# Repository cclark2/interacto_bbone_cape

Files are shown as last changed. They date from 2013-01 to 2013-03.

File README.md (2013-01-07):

Interacto BeagleBone Cape
=========================

Get your BeagleBone interactive with a triple axis accelerometer, gyroscope, and magnetometer, plus a 640x480 30fps camera! All sensors are digital and communicate via I2C to the BeagleBone. The camera frames are captured using the PRU.

Special thanks to <a href="http://www.sparkfun.com/">SparkFun</a> for use of their open-source EAGLE libraries.

## Project Links
- <a href="http://www.hitchhikeree.org/beaglebone_capes/interacto/">HitchhikerEE page</a>
- <a href="http://www.youtube.com/watch?v=t2w74zxGNqg">YouTube video</a>
- <a href="https://docs.google.com/folder/d/0B5HjtPsFD8u5ZUltQlZ1RDNVN1U/edit">Design files on Google Drive</a>
- <a href="http://beagleboard.org/CapeContest/entries/Interacto/">BeagleBone Cape Contest page</a>

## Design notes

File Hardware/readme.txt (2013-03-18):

Might be a good idea to go with OVM7690-R20A for the camera instead.
It's cheaper, probably more available, and has the same interface as the current part.

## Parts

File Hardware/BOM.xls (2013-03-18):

Qty | Value | Device | Package | Parts | MPN | Price | Total
1 |  | CAT24C256 | SOIC8 | U$1 | CAT24C256WI-GT3 | 0.56 | 0.56
1 |  | FE05-2 | FE05-2 | P6 | SSHQ-105-D-10-GT-LF | 0.5 | 0.5
2 |  | FE23-2 | FE23-2 | P8, P9 | SSHQ-123-D-10-GT-LF | 2.28 | 4.56
1 |  | LP3985 | SOT23-5 | U$10 | LP3985IM5-2.8/NOPB | 0.38 | 0.38
1 |  | LSM303DLHC | LGA14 | U$5 | LSM303DLHC | 6.35 | 6.35
1 |  | LSM330DLC | LGA28-4X5 | U$7 | LSM330DLC | 6.56 | 6.56
1 |  | SN74LVC1T45 | SOT23-6 | U$4 | SN74LVC1T45DBVR | 0.65 | 0.65
1 |  | SN74LVCH16T245 | TSSOP48 | U$13 | SN74LVCH16T245DGGR | 2.34 | 2.34
1 |  | TPS799XX | SOT23-5 | U$12 | TPS79915DDCR | 0.83 | 0.83
1 | 0 | R-US_R0402 | R0402 | R31 | ERJ-2GE0R00X | 0.07 | 0.07
12 | 0.1u | C-EUC0603 | C0603 | C1, C2, C3, C6, C14, C15, C23, C24, C25, C26, C27, C28 | VJ0603V104ZXXCW1BC | 0.06 | 0.72
1 | 0.22u | C-EUC0603 | C0603 | C7 | VJ0603V224MXJPW1BC | 0.06 | 0.06
1 | 100 | R-US_R0402 | R0402 | R27 | CR0402-JW-330GLF | 0.05 | 0.05
24 | 100 | R-US_R0402 | R0402 | R6, R8, R10, R11, R12, R13, R14, R15, R16, R17, R18, R19, R20, R21, R22, R23, R24, R25, R26, R28, R29, R32, R37, R38 | ERA-6AED101V | 0.09 | 2.16
1 | 10K | R-US_R0603 | R0603 | R9 | WR06X1002FTL | 0.02 | 0.02
3 | 10n | C-EUC0603 | C0603 | C16, C18, C21 | VJ0603Y103KXACW1BC | 0.06 | 0.18
2 | 10u | C-EUC0603 | C0603 | C4, C13 | LMK107BBJ106MALT | 0.64 | 1.28
1 | 150 | R-US_R0603 | R0603 | R33 | 302-150-RC | 0.04 | 0.04
3 | 1u | C-EUC0603 | C0603 | C17, C19, C20 | C1608X7R1C105K | 0.07 | 0.21
1 | 2.2u | C-EUC0603 | C0603 | C22 | C1608Y5V1C225Z | 0.08 | 0.08
1 | 219-02 | 219-02 | CTS-219-02 | S1 | 219-2MST | 0.58 | 0.58
3 | 4.75K | R-US_R0603 | R0603 | R2, R5, R7 | CR0603-FX-4751GLF | 0.04 | 0.12
1 | 4.7u | C-EUC0603 | C0603 | C5 | GRM188F51A475ZE20J | 0.1 | 0.1
2 | 5.6K, 5% | R-US_R0603 | R0603 | R1, R3 | RK73B1JTTDD562J | 0.06 | 0.12
1 | 50 | R-US_R0402 | R0402 | R36 | 302-49.9-RC | 0.04 | 0.04
2 | 50 | R-US_R0603 | R0603 | R34, R35 | 302-49.9-RC | 0.04 | 0.08
1 | TCM8230MD | TCM8230MD | TCM8230MD | U$3 | TCM8230MD | 9.95 | 9.95
1 | blue | LEDCHIPLED_0603 | CHIPLED_0603 | LED1 | HT-193NB-5589 | 0.15 | 0.15
2 | green | LEDCHIPLED_0603 | CHIPLED_0603 | LED2, LED3 | LG Q971-KN-1 | 0.1 | 0.2
 |  |  |  |  |  |  | 38.94

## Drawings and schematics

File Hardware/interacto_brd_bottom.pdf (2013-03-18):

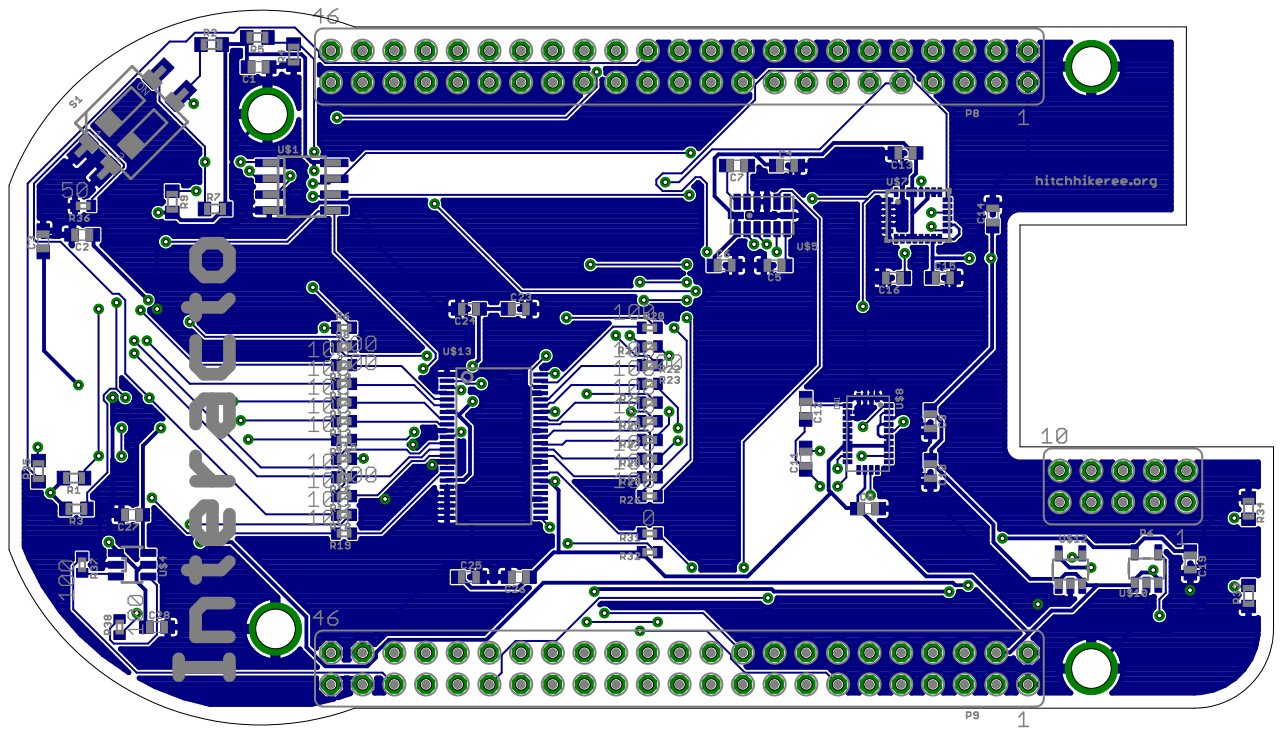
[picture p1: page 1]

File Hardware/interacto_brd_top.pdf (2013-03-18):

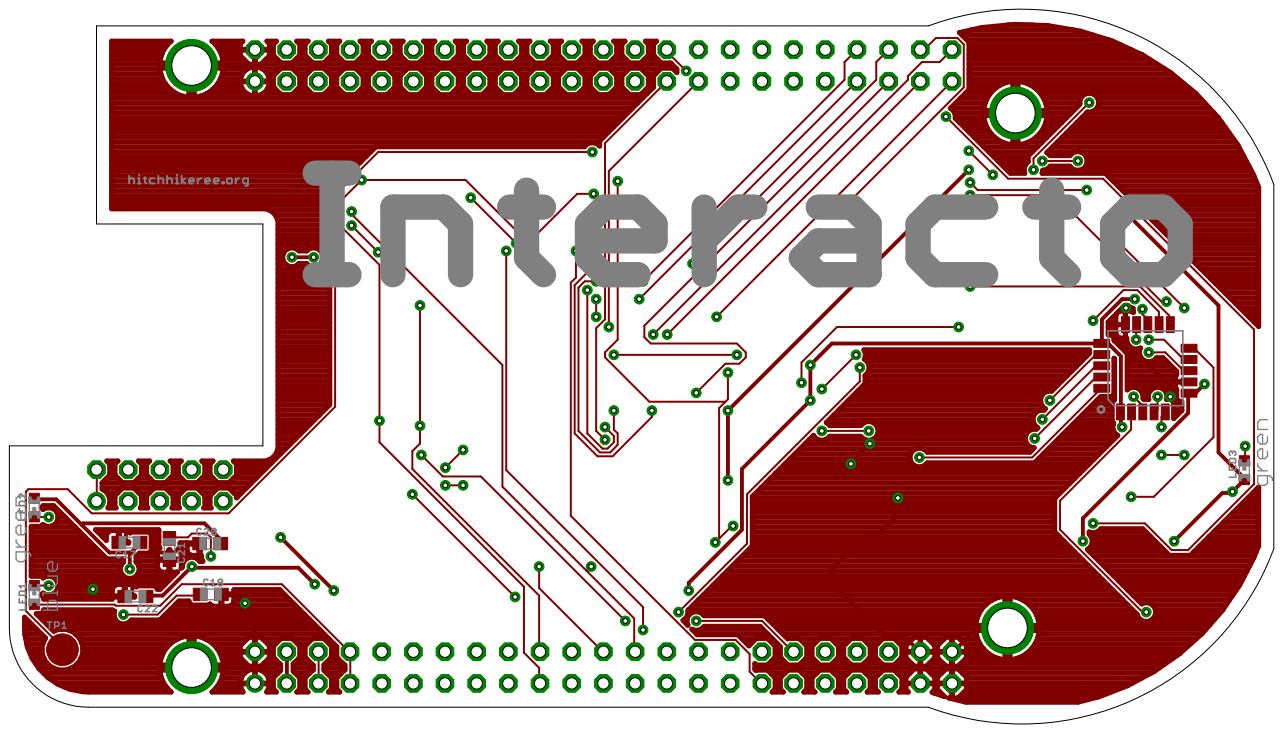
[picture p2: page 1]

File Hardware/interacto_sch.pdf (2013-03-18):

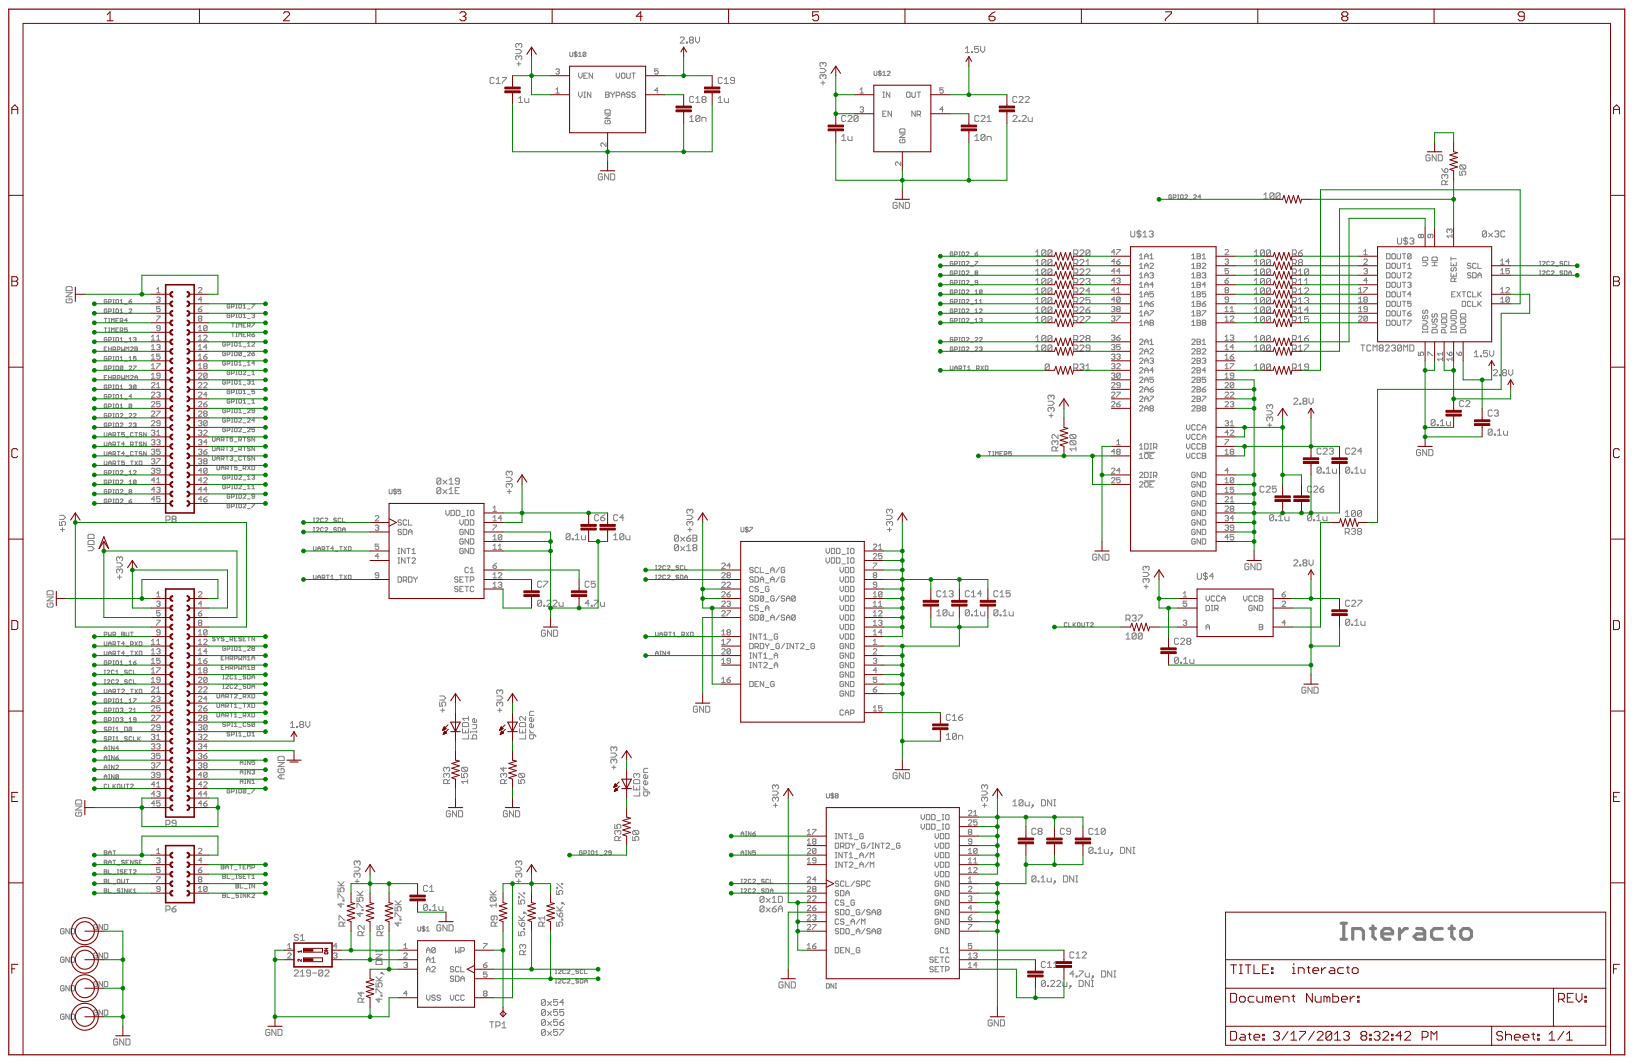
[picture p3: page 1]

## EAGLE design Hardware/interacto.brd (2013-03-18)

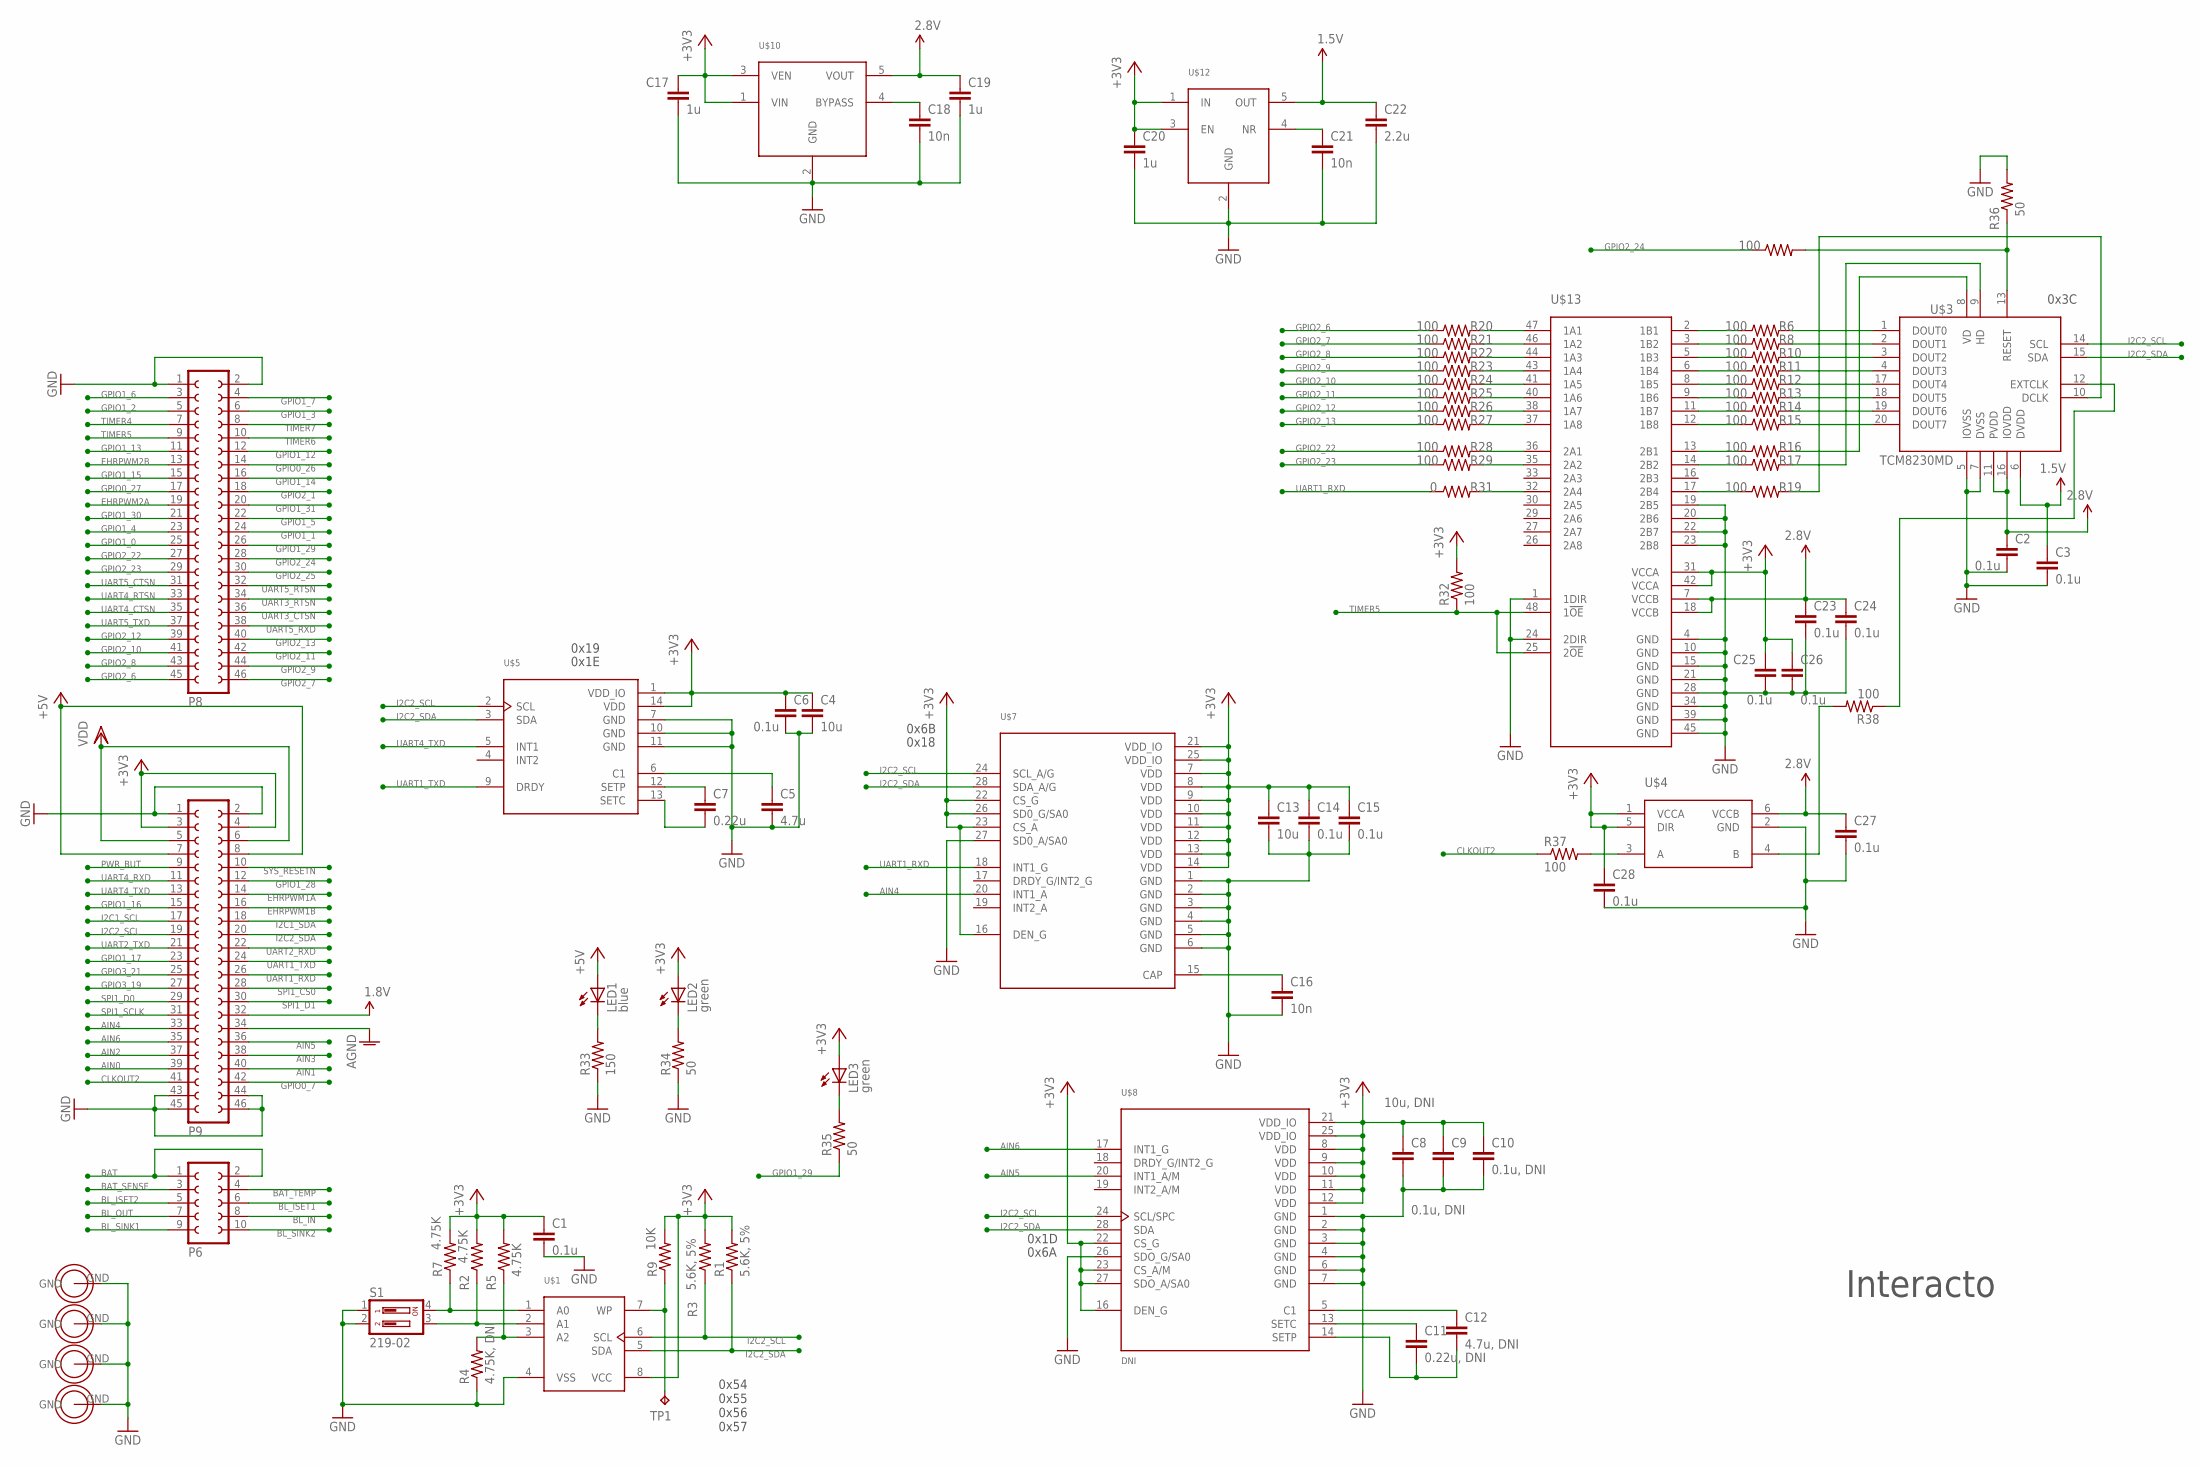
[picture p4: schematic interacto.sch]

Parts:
C1, C2, C3, C6, C14, C15, C23, C24, C25, C26, C27, C28: 0.1u; C0603; MPN VJ0603V104ZXXCW1BC
C4, C13: 10u; C0603; MPN LMK107BBJ106MALT
C5: 4.7u; C0603; MPN GRM188F51A475ZE20J
C7: 0.22u; C0603; MPN VJ0603V224MXJPW1BC
C8: 10u, DNI; C0603; MPN LMK107BBJ106MALT
C9, C10: 0.1u, DNI; C0603; MPN VJ0603V104ZXXCW1BC
C11: 0.22u, DNI; C0603; MPN VJ0603V224MXJPW1BC
C12: 4.7u, DNI; C0603; MPN GRM188F51A475ZE20J
C16, C18, C21: 10n; C0603; MPN VJ0603Y103KXACW1BC
C17, C19, C20: 1u; C0603; MPN C1608X7R1C105K
C22: 2.2u; C0603; MPN C1608Y5V1C225Z
H1, H2, H3, H4: HOLE
LED1: blue; CHIPLED_0603; MPN HT-193NB-5589
LED2, LED3: green; CHIPLED_0603; MPN LG Q971-KN-1
P6: FE05-2; MPN SSHQ-105-D-10-GT-LF
P8, P9: FE23-2; MPN SSHQ-123-D-10-GT-LF
R1, R3: 5.6K, 5%; R0603; MPN RK73B1JTTDD562J
R2, R5, R7: 4.75K; R0603; MPN CR0603-FX-4751GLF
R4: 4.75K, DNI; R0603; MPN CR0603-FX-4751GLF
R6, R8, R10, R11, R12, R13, R14, R15, R16, R17, R18, R19, R20, R21, R22, R23, R24, R25, R26, R28, R29, R32, R37, R38: 100; R0402; MPN ERA-6AED101V
R9: 10K; R0603; MPN WR06X1002FTL
R27: 100; R0402; MPN CR0402-JW-330GLF
R31: 0; R0402; MPN ERJ-2GE0R00X
R33: 150; R0603; MPN 302-150-RC
R34, R35: 50; R0603; MPN 302-49.9-RC
R36: 50; R0402; MPN 302-49.9-RC
S1: 219-02; CTS-219-02; MPN 219-2MST
TP1: TPB2,54; B2,54
U$1: CAT24C256; SOIC8; MPN CAT24C256WI-GT3
U$3: TCM8230MD; MPN TCM8230MD
U$4: SN74LVC1T45; SOT23-6; MPN SN74LVC1T45DBVR
U$5: LSM303DLHC; LGA14; MPN LSM303DLHC
U$7: LSM330DLC; LGA28-4X5; MPN LSM330DLC
U$8: DNI; LGA28; MPN LSM333D
U$10: LP3985; SOT23-5; MPN LP3985IM5-2.8/NOPB
U$12: TPS799XX; SOT23-5; MPN TPS79915DDCR
U$13: SN74LVCH16T245; TSSOP48; MPN SN74LVCH16T245DGGR

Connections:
1.5V: C3.1, C22.1, U$3.6 (DVDD), U$12.5 (OUT)
1.8V: P9.32
2.85V: C2.1, C19.1, C23.1, C24.1, C27.1, U$3.11 (PVDD), U$3.16 (IOVDD), U$4.6 (VCCB), U$10.5 (VOUT), U$13.7 (VCCB), U$13.18 (VCCB)
+3V3: C1.1, C4.1, C6.1, C8.1, C9.1, C10.1, C13.1, C14.1, C15.1, C17.1, C20.1, C25.1, C26.1, C28.1, LED2.A, LED3.A, P9.3, P9.4, R1.2, R2.2, R3.2, R5.2, R7.2, R9.2, R32.2, U$1.8 (VCC), U$4.1 (VCCA), U$4.5 (DIR), U$5.1 (VDD_IO), U$5.14 (VDD), U$7.7 (VDD), U$7.8 (VDD), U$7.9 (VDD), U$7.10 (VDD), U$7.11 (VDD), U$7.12 (VDD), U$7.13 (VDD), U$7.14 (VDD), U$7.16 (DEN_G), U$7.21 (VDD_IO), U$7.22 (CS_G), U$7.23 (CS_A), U$7.25 (VDD_IO), U$7.26 (SD0_G/SA0), U$8.8 (VDD), U$8.9 (VDD), U$8.10 (VDD), U$8.11 (VDD), U$8.12 (VDD), U$8.16 (DEN_G), U$8.21 (VDD_IO), U$8.22 (CS_G), U$8.23 (CS_A/M), U$8.25 (VDD_IO), U$8.27 (SDO_A/SA0), U$10.1 (VIN), U$10.3 (VEN), U$12.1 (IN), U$12.3 (EN), U$13.31 (VCCA), U$13.42 (VCCA)
+5V: LED1.A, P9.7, P9.8
AGND: P9.34
AIN0: P9.39
AIN1: P9.40
AIN2: P9.37
AIN3: P9.38
AIN4: P9.33, U$7.20 (INT1_A)
AIN5: P9.36, U$8.20 (INT1_A/M)
AIN6: P9.35, U$8.17 (INT1_G)
BAT: P6.1, P6.2
BAT_SENSE: P6.3
BAT_TEMP: P6.4
BL_IN: P6.8
BL_ISET1: P6.6
BL_ISET2: P6.5
BL_OUT: P6.7
BL_SINK1: P6.9
BL_SINK2: P6.10
CLKOUT2: P9.41, R37.1
EHRPWM1A: P9.14
EHRPWM1B: P9.16
EHRPWM2A: P8.19
EHRPWM2B: P8.13
GND: C1.2, C2.2, C3.2, C4.2, C5.2, C6.2, C8.2, C9.2, C10.2, C13.2, C14.2, C15.2, C16.2, C17.2, C18.2, C19.2, C20.2, C21.2, C22.2, C23.2, C24.2, C25.2, C26.2, C27.2, C28.2, H1.GND, H2.GND, H3.GND, H4.GND, P8.1, P8.2, P9.1, P9.2, P9.43, P9.44, P9.45, P9.46, R4.1, R33.1, R34.1, R36.2, S1.1, S1.2, U$1.4 (VSS), U$3.5 (IOVSS), U$3.7 (DVSS), U$4.2 (GND), U$5.7 (GND), U$5.10 (GND), U$5.11 (GND), U$7.1 (GND), U$7.2 (GND), U$7.3 (GND), U$7.4 (GND), U$7.5 (GND), U$7.6 (GND), U$7.27 (SD0_A/SA0), U$8.1 (GND), U$8.2 (GND), U$8.3 (GND), U$8.4 (GND), U$8.6 (GND), U$8.7 (GND), U$8.26 (SDO_G/SA0), U$10.2 (GND), U$12.2 (GND), U$13.1 (1DIR), U$13.4 (GND), U$13.10 (GND), U$13.15 (GND), U$13.19 (2B5), U$13.20 (2B6), U$13.21 (GND), U$13.22 (2B7), U$13.23 (2B8), U$13.24 (2DIR), U$13.28 (GND), U$13.34 (GND), U$13.39 (GND), U$13.45 (GND)
GPIO0_7: P9.42
GPIO0_26: P8.14
GPIO0_27: P8.17
GPIO1_0: P8.25
GPIO1_1: P8.24
GPIO1_2: P8.5
GPIO1_3: P8.6
GPIO1_4: P8.23
GPIO1_5: P8.22
GPIO1_6: P8.3
GPIO1_7: P8.4
GPIO1_12: P8.12
GPIO1_13: P8.11
GPIO1_14: P8.16
GPIO1_15: P8.15
GPIO1_16: P9.15
GPIO1_17: P9.23
GPIO1_28: P9.12
GPIO1_29: P8.26, R35.1
GPIO1_30: P8.21
GPIO1_31: P8.20
GPIO2_1: P8.18
GPIO2_6: P8.45, R20.1
GPIO2_7: P8.46, R21.1
GPIO2_8: P8.43, R22.1
GPIO2_9: P8.44, R23.1
GPIO2_10: P8.41, R24.1
GPIO2_11: P8.42, R25.1
GPIO2_12: P8.39, R26.1
GPIO2_13: P8.40, R27.1
GPIO2_22: P8.27, R28.1
GPIO2_23: P8.29, R29.1
GPIO2_24: P8.28, R18.1
GPIO2_25: P8.30
GPIO3_19: P9.27
GPIO3_21: P9.25
I2C1_SCL: P9.17
I2C1_SDA: P9.18
I2C2_SCL: P9.19, R3.1, U$1.6 (SCL), U$3.14 (SCL), U$5.2 (SCL), U$7.24 (SCL_A/G), U$8.24 (SCL/SPC)
I2C2_SDA: P9.20, R1.1, U$1.5 (SDA), U$3.15 (SDA), U$5.3 (SDA), U$7.28 (SDA_A/G), U$8.28 (SDA)
unnamed: R7.1, S1.4, U$1.1 (A0)
unnamed: R2.1, S1.3, U$1.2 (A1)
unnamed: R4.2, R5.1, U$1.3 (A2)
unnamed: R6.1, U$13.2 (1B1)
unnamed: R9.1, TP1.TP, U$1.7 (WP)
unnamed: R8.1, U$13.3 (1B2)
unnamed: R10.1, U$13.5 (1B3)
unnamed: R11.1, U$13.6 (1B4)
unnamed: R12.1, U$13.8 (1B5)
unnamed: R13.1, U$13.9 (1B6)
unnamed: R14.1, U$13.11 (1B7)
unnamed: R15.1, U$13.12 (1B8)
unnamed: R19.2, U$3.10 (DCLK)
unnamed: R16.2, U$3.8 (VD)
unnamed: R17.2, U$3.9 (HD)
unnamed: R18.2, R36.1, U$3.13 (RESET)
unnamed: R28.2, U$13.36 (2A1)
unnamed: LED1.C, R33.2
unnamed: LED2.C, R34.2
unnamed: R16.1, U$13.13 (2B1)
unnamed: R17.1, U$13.14 (2B2)
unnamed: R19.1, U$13.17 (2B4)
unnamed: R6.2, U$3.1 (DOUT0)
unnamed: R8.2, U$3.2 (DOUT1)
unnamed: R10.2, U$3.3 (DOUT2)
unnamed: R11.2, U$3.4 (DOUT3)
unnamed: R12.2, U$3.17 (DOUT4)
unnamed: R13.2, U$3.18 (DOUT5)
unnamed: R14.2, U$3.19 (DOUT6)
unnamed: R15.2, U$3.20 (DOUT7)
unnamed: R20.2, U$13.47 (1A1)
unnamed: R21.2, U$13.46 (1A2)
unnamed: R22.2, U$13.44 (1A3)
unnamed: R23.2, U$13.43 (1A4)
unnamed: R24.2, U$13.41 (1A5)
unnamed: R25.2, U$13.40 (1A6)
unnamed: R26.2, U$13.38 (1A7)
unnamed: R27.2, U$13.37 (1A8)
unnamed: R29.2, U$13.35 (2A2)
unnamed: R31.2, U$13.32 (2A4)
unnamed: LED3.C, R35.2
unnamed: C7.1, U$5.12 (SETP)
unnamed: C7.2, U$5.13 (SETC)
unnamed: C5.1, U$5.6 (C1)
unnamed: C16.1, U$7.15 (CAP)
unnamed: C11.1, U$8.13 (SETC)
unnamed: C11.2, C12.2, U$8.14 (SETP)
unnamed: C12.1, U$8.5 (C1)
unnamed: C18.1, U$10.4 (BYPASS)
unnamed: R38.1, U$3.12 (EXTCLK)
unnamed: R37.2, U$4.3 (A)
unnamed: C21.1, U$12.4 (NR)
unnamed: R38.2, U$4.4 (B)
PWR_BUT: P9.9
SPI1_CS0: P9.28
SPI1_D0: P9.29
SPI1_D1: P9.30
SPI1_SCLK: P9.31
SYS_RESETN: P9.10
TIMER4: P8.7
TIMER5: P8.9, R32.1, U$13.25 (2!OE), U$13.48 (1!OE)
TIMER6: P8.10
TIMER7: P8.8
UART1_RXD: P9.26, R31.1, U$7.18 (INT1_G)
UART1_TXD: P9.24, U$5.9 (DRDY)
UART2_RXD: P9.22
UART2_TXD: P9.21
UART3_CTSN: P8.36
UART3_RTSN: P8.34
UART4_CTSN: P8.35
UART4_RTSN: P8.33
UART4_RXD: P9.11
UART4_TXD: P9.13, U$5.5 (INT1)
UART5_CTSN: P8.31
UART5_RTSN: P8.32
UART5_RXD: P8.38
UART5_TXD: P8.37
VDD: P9.5, P9.6

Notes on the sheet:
Interacto
0x54 0x55 0x56 0x57
0x19
0x1E
0x18
0x6B
0x1D
0x6A
0x3C

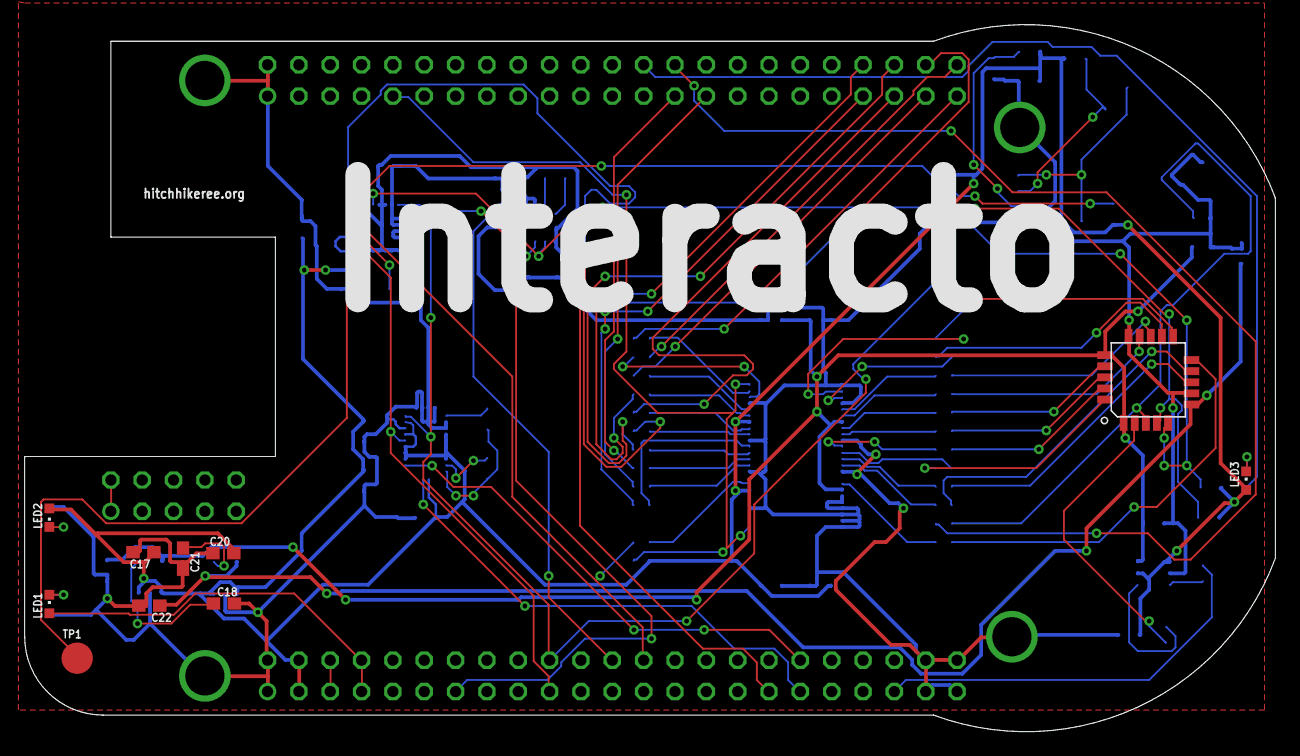
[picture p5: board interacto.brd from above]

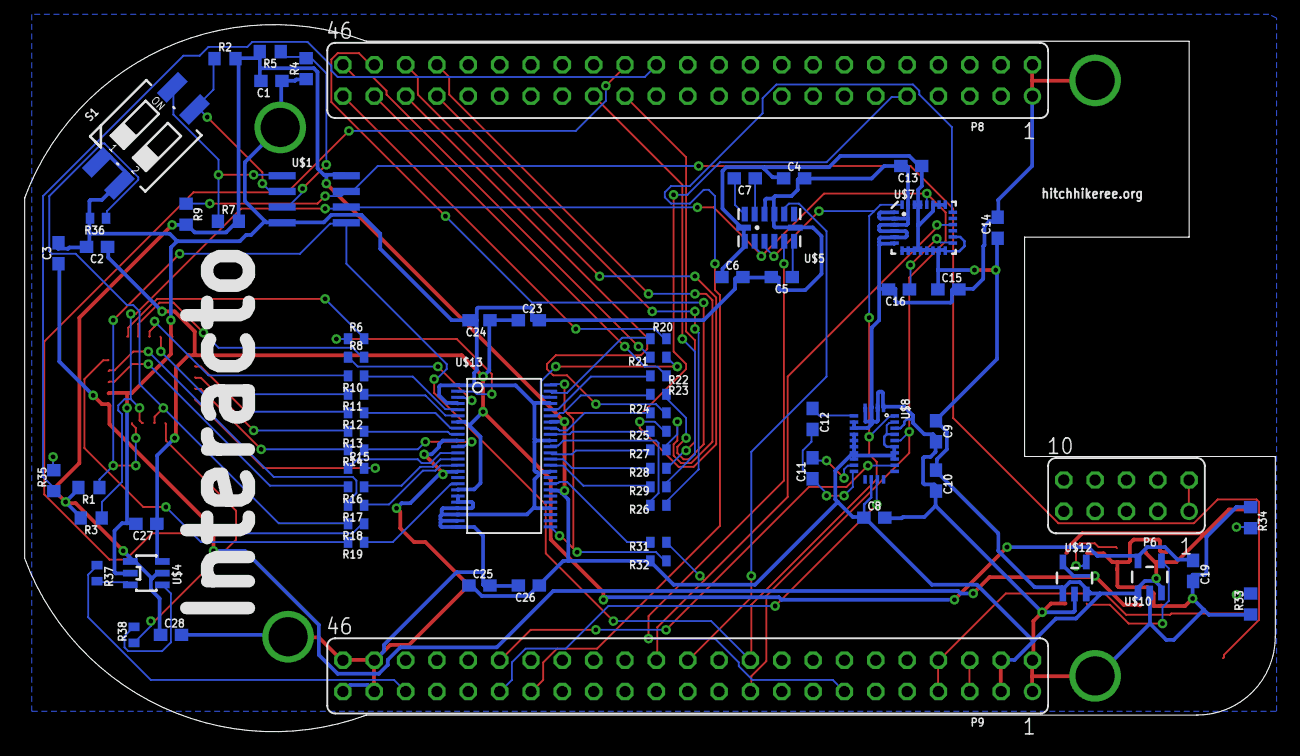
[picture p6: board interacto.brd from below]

Board: 2 copper layers, 101.4 x 57.3 mm, 86 parts (72 on the bottom side), 82 nets.

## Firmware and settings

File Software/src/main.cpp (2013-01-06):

//
//      nunchuck.c
//

#ifndef PORT
//#define PORT "/dev/i2c-1"    // reserved for capes and requiring pullup resistors
#define PORT "/dev/i2c-3"      // p9:pin19=SCL, p9:pin20:SDA
#endif


// 303 accelerometer
#define ADDR_ACCEL_303  0x19            // wii nunchuck address: 0x52
// 303 magnetometer
#define ADDR_MAG_303  0x1e            // wii nunchuck address: 0x52
// 330 accelerometer
#define ADDR_ACCEL_330  0x18            // wii nunchuck address: 0x52
// 330 gyroscope
#define ADDR_GYRO_330  0x6b            // wii nunchuck address: 0x52

// camera
#define ADDR_CAM  0x3C            // wii nunchuck address: 0x52


#include <stdio.h>
#include <fcntl.h>
#include <stdlib.h>
#include <linux/i2c-dev.h>
#include <sys/ioctl.h>
#include <unistd.h>
#include <sys/mman.h>
#include <errno.h>
#include <string.h>
#include <stdint.h>

#include <iostream>
#include <fstream>
#include <iomanip>
#include <stdexcept>
#include <sstream>

#include <prussdrv.h>
#include <pruss_intc_mapping.h>
#include <opencv2/opencv.hpp>
#include <opencv2/core/core.hpp>
#include <opencv2/highgui/highgui.hpp>

#include "mem_map.h"

#define error(x...) { fprintf(stderr, "\nE%d: ", __LINE__); fprintf(stderr, x); fprintf(stderr, "\n\n"); exit(1); }

#define DDR_BASEADDR 0x80000000
#define OFFSET_DDR	 (224*1024*1024)
#define PRU_DDR_SIZE (16*1024*1024)
#define PRU0_DDR    ( DDR_BASEADDR + OFFSET_DDR )
#define PRU1_DDR    ( PRU0_DDR +PRU_DDR_SIZE)


int main()
{
  // gpio 2.3 (timer7) = lcd data gate = 67 (gpmc_oen_ren)
  // gpio 1.6 = lcd cs = 38 (gpmc_ad6)
  // gpio 1.7 = lcd rs = 39 (gpmc_ad7)
  // gpio 1.2 = lcd wr = 34 (gpmc_ad2)
  // gpio 1.28 = lcd rd = 60 (gpmc_ben1)
  // gpio 2.2 (timer4) lcd reset 66 (gpmc_advn_ale)
  
  // gpio 3.14 (spi1_sclk) = lcd db8 = pru0.0 = 110 (mcasp0_aclkx)
  // gpio 3.15 (spi1_d0) = lcd db9 = pru0.1 = 111 (mcasp0_fsx)
  // gpio 3.16 (spi1_d1) = lcd db10 = pru0.2 = 112 (mcasp0_axr0)
  // gpio 3.17 (spi1_cs0) = lcd db11 = pru0.3 = 113 (mcasp0_ahclkr)
  // gpio 3.19 = lcd db12 = pru0.5 =115 (mcasp0_fsr)
  // gpio 3.21 = lcd db13 = pru0.7 = 117 (mcasp0_ahclkx)
  // gpio 1.12 = lcd db14 = pru0.14 = 44 (gpmc_ad12)
  // gpio 1.13 = lcd db15 = pru0.15 = 45 (gpmc_ad13)
  
  system( "echo 67 > /sys/class/gpio/unexport" );
  system( "echo 38 > /sys/class/gpio/unexport" );
  system( "echo 39 > /sys/class/gpio/unexport" );
  system( "echo 34 > /sys/class/gpio/unexport" );
  system( "echo 60 > /sys/class/gpio/unexport" );
  system( "echo 66 > /sys/class/gpio/unexport" );
  
  if( 0 != system( "echo 07 > /sys/kernel/debug/omap_mux/gpmc_oen_ren" ) )
    throw std::runtime_error( "Failed to set mux for lcd data gate" );
  if( 0 != system( "echo 07 > /sys/kernel/debug/omap_mux/gpmc_ad6" ) )
    throw std::runtime_error( "Failed to set mux for lcd cs" );
  if( 0 != system( "echo 07 > /sys/kernel/debug/omap_mux/gpmc_ad7" ) )
    throw std::runtime_error( "Failed to set mux for lcd rs" );
  if( 0 != system( "echo 07 > /sys/kernel/debug/omap_mux/gpmc_ad2" ) )
    throw std::runtime_error( "Failed to set mux for lcd wr" );
  if( 0 != system( "echo 07 > /sys/kernel/debug/omap_mux/gpmc_ben1" ) )
    throw std::runtime_error( "Failed to set mux for lcd rd" );
  if( 0 != system( "echo 07 > /sys/kernel/debug/omap_mux/gpmc_advn_ale" ) )
    throw std::runtime_error( "Failed to set mux for lcd reset" );
  
  if( 0 != system( "echo 67 > /sys/class/gpio/export" ) )
    throw std::runtime_error( "Failed to export lcd data gate" );
  if( 0 != system( "echo 38 > /sys/class/gpio/export" ) )
    throw std::runtime_error( "Failed to export lcd cs" );
  if( 0 != system( "echo 39 > /sys/class/gpio/export" ) )
    throw std::runtime_error( "Failed to export lcd rs" );
  if( 0 != system( "echo 34 > /sys/class/gpio/export" ) )
    throw std::runtime_error( "Failed to export lcd wr" );
  if( 0 != system( "echo 60 > /sys/class/gpio/export" ) )
    throw std::runtime_error( "Failed to export lcd rd" );
  if( 0 != system( "echo 66 > /sys/class/gpio/export" ) )
    throw std::runtime_error( "Failed to export lcd reset" );
    
  if( 0 != system( "echo out > /sys/class/gpio/gpio67/direction" ) )
    throw std::runtime_error( "Failed to set lcd data gate gpio direction" );
  if( 0 != system( "echo out > /sys/class/gpio/gpio38/direction" ) )
    throw std::runtime_error( "Failed to set lcd cs gpio direction" );
  if( 0 != system( "echo out > /sys/class/gpio/gpio39/direction" ) )
    throw std::runtime_error( "Failed to set lcd rs gpio direction" );
  if( 0 != system( "echo out > /sys/class/gpio/gpio34/direction" ) )
    throw std::runtime_error( "Failed to set lcd wr gpio direction" );
  if( 0 != system( "echo out > /sys/class/gpio/gpio60/direction" ) )
    throw std::runtime_error( "Failed to set lcd rd gpio direction" );
  if( 0 != system( "echo out > /sys/class/gpio/gpio66/direction" ) )
    throw std::runtime_error( "Failed to set lcd reset gpio direction" );
    
  if( 0 != system( "echo 05 > /sys/kernel/debug/omap_mux/mcasp0_aclkx" ) )
    throw std::runtime_error( "Failed to set mux for lcd db8" );
  if( 0 != system( "echo 05 > /sys/kernel/debug/omap_mux/mcasp0_fsx" ) )
    throw std::runtime_error( "Failed to set mux for lcd db9" );
  if( 0 != system( "echo 05 > /sys/kernel/debug/omap_mux/mcasp0_axr0" ) )
    throw std::runtime_error( "Failed to set mux for lcd db10" );
  if( 0 != system( "echo 05 > /sys/kernel/debug/omap_mux/mcasp0_ahclkr" ) )
    throw std::runtime_error( "Failed to set mux for lcd db11" );
  if( 0 != system( "echo 05 > /sys/kernel/debug/omap_mux/mcasp0_fsr" ) )
    throw std::runtime_error( "Failed to set mux for lcd db12" );
  if( 0 != system( "echo 05 > /sys/kernel/debug/omap_mux/mcasp0_ahclkx" ) )
    throw std::runtime_error( "Failed to set mux for lcd db13" );
  if( 0 != system( "echo 06 > /sys/kernel/debug/omap_mux/gpmc_ad12" ) )
    throw std::runtime_error( "Failed to set mux for lcd db14" );
  if( 0 != system( "echo 06 > /sys/kernel/debug/omap_mux/gpmc_ad13" ) )
    throw std::runtime_error( "Failed to set mux for lcd db15" );
  
  
  
  std::ofstream lcd_pru_gate( "/sys/class/gpio/gpio67/value" );
  std::ofstream lcd_pru_cs( "/sys/class/gpio/gpio38/value" );
  std::ofstream lcd_pru_rs( "/sys/class/gpio/gpio39/value" );
  std::ofstream lcd_pru_wr( "/sys/class/gpio/gpio34/value" );
  std::ofstream lcd_pru_rd( "/sys/class/gpio/gpio60/value" );
  std::ofstream lcd_pru_reset( "/sys/class/gpio/gpio66/value" );
  
  if( !lcd_pru_gate.is_open() || !lcd_pru_cs.is_open() || !lcd_pru_rs.is_open() || !lcd_pru_wr.is_open()
      || !lcd_pru_rd.is_open() || !lcd_pru_reset.is_open()  )
    throw std::runtime_error( "Failed to open lcd pru gpios" );

 
  lcd_pru_cs << '1' << std::endl;
  lcd_pru_rs << '1' << std::endl;
  lcd_pru_wr << '1' << std::endl;
  lcd_pru_rd << '1' << std::endl;
  lcd_pru_gate << '0' << std::endl;
  lcd_pru_reset << '0' << std::endl;
  usleep( 100000 );
  lcd_pru_reset << '1' << std::endl;

  
  
  
  
  
  
  // gpio 0.22 (ehrpwm2a) = lcd cs = 22 (gpmc_ad8)
  // gpio 0.23 (ehrpwm2b) = lcd rs = 23 (gpmc_ad9)
  // gpio 0.30 (uart4_rxd) = lcd wr = 30 (gpmc_wait0)
  // gpio 1.1 = lcd rd = 33 (gpmc_ad1)
  // gpio 0.26 = lcd reset = 26 (gpmc_ad10)
  // gpio 0.2 (uart2_rxd) = lcd db8 = 2 (spi0_sclk)
  // gpio 0.3 (uart2_txd) = lcd db9 = 3 (spi0_d0)
  // gpio 0.4 (i2c1_sda) = lcd db10 = 4 (spi0_d1)
  // gpio 0.5 (i2c1_scl) = lcd db11 = 5 (spi0_cs0)
  // gpio 0.8 (uart4_ctsn) = lcd db12 = 8 (lcd_data12)
  // gpio 0.9 (uart4_rtsn) = lcd db13 = 9 (lcd_data13)
  // gpio 0.10 (uart5_ctsn) = lcd db14 = 10 (lcd_data14)
  // gpio 0.11 (uart5_rtsn) = lcd db15 = 11 (lcd_data15)
 
  system( "echo 22 > /sys/class/gpio/unexport" );
  system( "echo 23 > /sys/class/gpio/unexport" );
  system( "echo 30 > /sys/class/gpio/unexport" );
  system( "echo 33 > /sys/class/gpio/unexport" );
  system( "echo 26 > /sys/class/gpio/unexport" );
  system( "echo 2 > /sys/class/gpio/unexport" );
  system( "echo 3 > /sys/class/gpio/unexport" );
  system( "echo 4 > /sys/class/gpio/unexport" );
  system( "echo 5 > /sys/class/gpio/unexport" );
  system( "echo 8 > /sys/class/gpio/unexport" );
  system( "echo 9 > /sys/class/gpio/unexport" );
  system( "echo 10 > /sys/class/gpio/unexport" );
  system( "echo 11 > /sys/class/gpio/unexport" );
  
  if( 0 != system( "echo 07 > /sys/kernel/debug/omap_mux/gpmc_ad8" ) )
    throw std::runtime_error( "Failed to set mux for lcd cs" );
  if( 0 != system( "echo 07 > /sys/kernel/debug/omap_mux/gpmc_ad9" ) )
    throw std::runtime_error( "Failed to set mux for lcd rs" );
  if( 0 != system( "echo 07 > /sys/kernel/debug/omap_mux/gpmc_wait0" ) )
    throw std::runtime_error( "Failed to set mux for lcd wr" );
  if( 0 != system( "echo 07 > /sys/kernel/debug/omap_mux/gpmc_ad1" ) )
    throw std::runtime_error( "Failed to set mux for lcd rd" );
  if( 0 != system( "echo 07 > /sys/kernel/debug/omap_mux/gpmc_ad10" ) )
    throw std::runtime_error( "Failed to set mux for lcd reset" );
  if( 0 != system( "echo 07 > /sys/kernel/debug/omap_mux/spi0_sclk" ) )
    throw std::runtime_error( "Failed to set mux for lcd db8" );
  if( 0 != system( "echo 07 > /sys/kernel/debug/omap_mux/spi0_d0" ) )
    throw std::runtime_error( "Failed to set mux for lcd db9" );
  if( 0 != system( "echo 07 > /sys/kernel/debug/omap_mux/spi0_d1" ) )
    throw std::runtime_error( "Failed to set mux for lcd db10" );
  if( 0 != system( "echo 07 > /sys/kernel/debug/omap_mux/spi0_cs0" ) )
    throw std::runtime_error( "Failed to set mux for lcd db11" );
  if( 0 != system( "echo 07 > /sys/kernel/debug/omap_mux/lcd_data12" ) )
    throw std::runtime_error( "Failed to set mux for lcd db12" );
  if( 0 != system( "echo 07 > /sys/kernel/debug/omap_mux/lcd_data13" ) )
    throw std::runtime_error( "Failed to set mux for lcd db13" );
  if( 0 != system( "echo 07 > /sys/kernel/debug/omap_mux/lcd_data14" ) )
    throw std::runtime_error( "Failed to set mux for lcd db14" );
  if( 0 != system( "echo 07 > /sys/kernel/debug/omap_mux/lcd_data15" ) )
    throw std::runtime_error( "Failed to set mux for lcd db15" );
    
  if( 0 != system( "echo 22 > /sys/class/gpio/export" ) )
    throw std::runtime_error( "Failed to export lcd cs" );
  if( 0 != system( "echo 23 > /sys/class/gpio/export" ) )
    throw std::runtime_error( "Failed to export lcd rs" );
  if( 0 != system( "echo 30 > /sys/class/gpio/export" ) )
    throw std::runtime_error( "Failed to export lcd wr" );
  if( 0 != system( "echo 33 > /sys/class/gpio/export" ) )
    throw std::runtime_error( "Failed to export lcd rd" );
  if( 0 != system( "echo 26 > /sys/class/gpio/export" ) )
    throw std::runtime_error( "Failed to export lcd reset" );
  if( 0 != system( "echo 2 > /sys/class/gpio/export" ) )
    throw std::runtime_error( "Failed to export lcd db8" );
  if( 0 != system( "echo 3 > /sys/class/gpio/export" ) )
    throw std::runtime_error( "Failed to export lcd db9" );
  if( 0 != system( "echo 4 > /sys/class/gpio/export" ) )
    throw std::runtime_error( "Failed to export lcd db10" );
  if( 0 != system( "echo 5 > /sys/class/gpio/export" ) )
    throw std::runtime_error( "Failed to export lcd db11" );
  if( 0 != system( "echo 8 > /sys/class/gpio/export" ) )
    throw std::runtime_error( "Failed to export lcd db12" );
  if( 0 != system( "echo 9 > /sys/class/gpio/export" ) )
    throw std::runtime_error( "Failed to export lcd db13" );
  if( 0 != system( "echo 10 > /sys/class/gpio/export" ) )
    throw std::runtime_error( "Failed to export lcd db14" );
  if( 0 != system( "echo 11 > /sys/class/gpio/export" ) )
    throw std::runtime_error( "Failed to export lcd db15" );
    
  if( 0 != system( "echo out > /sys/class/gpio/gpio22/direction" ) )
    throw std::runtime_error( "Failed to set lcd cs gpio direction" );
  if( 0 != system( "echo out > /sys/class/gpio/gpio23/direction" ) )
    throw std::runtime_error( "Failed to set lcd rs gpio direction" );
  if( 0 != system( "echo out > /sys/class/gpio/gpio30/direction" ) )
    throw std::runtime_error( "Failed to set lcd wr gpio direction" );
  if( 0 != system( "echo out > /sys/class/gpio/gpio33/direction" ) )
    throw std::runtime_error( "Failed to set lcd rd gpio direction" );
  if( 0 != system( "echo out > /sys/class/gpio/gpio26/direction" ) )
    throw std::runtime_error( "Failed to set lcd reset gpio direction" );
  if( 0 != system( "echo out > /sys/class/gpio/gpio2/direction" ) )
    throw std::runtime_error( "Failed to set lcd db8 gpio direction" );
  if( 0 != system( "echo out > /sys/class/gpio/gpio3/direction" ) )
    throw std::runtime_error( "Failed to set lcd db9 gpio direction" );
  if( 0 != system( "echo out > /sys/class/gpio/gpio4/direction" ) )
    throw std::runtime_error( "Failed to set lcd db10 gpio direction" );
  if( 0 != system( "echo out > /sys/class/gpio/gpio5/direction" ) )
    throw std::runtime_error( "Failed to set lcd db11 gpio direction" );
  if( 0 != system( "echo out > /sys/class/gpio/gpio8/direction" ) )
    throw std::runtime_error( "Failed to set lcd db12 gpio direction" );
  if( 0 != system( "echo out > /sys/class/gpio/gpio9/direction" ) )
    throw std::runtime_error( "Failed to set lcd db13 gpio direction" );
  if( 0 != system( "echo out > /sys/class/gpio/gpio10/direction" ) )
    throw std::runtime_error( "Failed to set lcd db14 gpio direction" );
  if( 0 != system( "echo out > /sys/class/gpio/gpio11/direction" ) )
    throw std::runtime_error( "Failed to set lcd db15 gpio direction" );
    

    
    
    
  std::ofstream lcd_cs( "/sys/class/gpio/gpio22/value" );
  std::ofstream lcd_rs( "/sys/class/gpio/gpio23/value" );
  std::ofstream lcd_wr( "/sys/class/gpio/gpio30/value" );
  std::ofstream lcd_rd( "/sys/class/gpio/gpio33/value" );
  std::ofstream lcd_reset( "/sys/class/gpio/gpio26/value" );
  std::ofstream lcd_db8( "/sys/class/gpio/gpio2/value" );
  std::ofstream lcd_db9( "/sys/class/gpio/gpio3/value" );
  std::ofstream lcd_db10( "/sys/class/gpio/gpio4/value" );
  std::ofstream lcd_db11( "/sys/class/gpio/gpio5/value" );
  std::ofstream lcd_db12( "/sys/class/gpio/gpio8/value" );
  std::ofstream lcd_db13( "/sys/class/gpio/gpio9/value" );
  std::ofstream lcd_db14( "/sys/class/gpio/gpio10/value" );
  std::ofstream lcd_db15( "/sys/class/gpio/gpio11/value" );
  
  if( !lcd_cs.is_open() || !lcd_rs.is_open() || !lcd_wr.is_open() || !lcd_rd.is_open() || 
      !lcd_reset.is_open() || !lcd_db8.is_open() || !lcd_db9.is_open() || !lcd_db10.is_open() ||
      !lcd_db11.is_open() || !lcd_db12.is_open() || !lcd_db13.is_open() || !lcd_db14.is_open() ||
      !lcd_db15.is_open() )
    throw std::runtime_error( "Failed to open lcd gpios" );

  lcd_cs << '1' << std::endl;
  lcd_rs << '1' << std::endl;
  lcd_wr << '1' << std::endl;
  lcd_rd << '1' << std::endl;
  lcd_reset << '0' << std::endl;
  usleep( 100000 );
  lcd_reset << '1' << std::endl;
  lcd_db8 << '0' << std::endl;
  lcd_db9 << '0' << std::endl;
  lcd_db10 << '0' << std::endl;
  lcd_db11 << '0' << std::endl;
  lcd_db12 << '0' << std::endl;
  lcd_db13 << '0' << std::endl;
  lcd_db14 << '0' << std::endl;
  lcd_db15 << '0' << std::endl;

  
  

  
  // gpio 2.24 = cam reset = 88 (lcd_pclk)
  // gpio 1.29 = cam led = 61 (gpmc_csn0)
  // gpio 2.5 (timer5) = cam data gate = 69 (gpmc_ben0_cle)

  // gpio 2.6 = cam data 0 = pru1.0 = 70 (lcd_data0)
  // gpio 2.7 = cam data 1 = pru1.1 = 71 (lcd_data1)
  // gpio 2.8 = cam data 2 = pru1.2 = 72 (lcd_data2)
  // gpio 2.9 = cam data 3 = pru1.3 = 73 (lcd_data3)
  // gpio 2.10 = cam data 4 = pru1.4 = 74 (lcd_data4)
  // gpio 2.11 = cam data 5 = pru1.5 = 75 (lcd_data5)
  // gpio 2.12 = cam data 6 = pru1.6 = 76 (lcd_data6)
  // gpio 2.13 = cam data 7 = pru1.7 = 77 (lcd_data7)
  // gpio 2.22 = cam vsync = pru1.8 = 86 (lcd_vsync)
  // gpio 2.23 = cam hsync = pru1.9 = 87 (lcd_hsync)
  // gpio 0.14 (uart1_rxd) = cam clock = pru1.16 = 14 (uart1_rxd)

  system( "echo 88 > /sys/class/gpio/unexport" );
  system( "echo 61 > /sys/class/gpio/unexport" );
  system( "echo 69 > /sys/class/gpio/unexport" );
  

  if( 0 != system( "echo 07 > /sys/kernel/debug/omap_mux/lcd_pclk" ) )
    throw std::runtime_error( "Failed to set mux for cam reset gpio" );
  if( 0 != system( "echo 07 > /sys/kernel/debug/omap_mux/gpmc_csn0" ) )
    throw std::runtime_error( "Failed to set mux for cam led gpio" );
  if( 0 != system( "echo 07 > /sys/kernel/debug/omap_mux/gpmc_ben0_cle" ) )
    throw std::runtime_error( "Failed to set mux for cam data gate gpio" );
    
  if( 0 != system( "echo 88 > /sys/class/gpio/export" ) )
    throw std::runtime_error( "Failed to export cam reset gpio" );
  if( 0 != system( "echo 61 > /sys/class/gpio/export" ) )
    throw std::runtime_error( "Failed to export cam led gpio" );
  if( 0 != system( "echo 69 > /sys/class/gpio/export" ) )
    throw std::runtime_error( "Failed to export cam data gate gpio" );
    
  if( 0 != system( "echo out > /sys/class/gpio/gpio88/direction" ) )
    throw std::runtime_error( "Failed to set cam reset gpio direction" );
  if( 0 != system( "echo out > /sys/class/gpio/gpio61/direction" ) )
    throw std::runtime_error( "Failed to set cam led gpio direction" );
  if( 0 != system( "echo out > /sys/class/gpio/gpio69/direction" ) )
    throw std::runtime_error( "Failed to set cam data gate gpio direction" );
    
  if( 0 != system( "echo 36 > /sys/kernel/debug/omap_mux/lcd_data0" ) )
    throw std::runtime_error( "Failed to set mux for cam data 0 pru" );
  if( 0 != system( "echo 36 > /sys/kernel/debug/omap_mux/lcd_data1" ) )
    throw std::runtime_error( "Failed to set mux for cam data 1 pru" );
  if( 0 != system( "echo 36 > /sys/kernel/debug/omap_mux/lcd_data2" ) )
    throw std::runtime_error( "Failed to set mux for cam data 2 pru" );
  if( 0 != system( "echo 36 > /sys/kernel/debug/omap_mux/lcd_data3" ) )
    throw std::runtime_error( "Failed to set mux for cam data 3 pru" );
  if( 0 != system( "echo 36 > /sys/kernel/debug/omap_mux/lcd_data4" ) )
    throw std::runtime_error( "Failed to set mux for cam data 4 pru" );
  if( 0 != system( "echo 36 > /sys/kernel/debug/omap_mux/lcd_data5" ) )
    throw std::runtime_error( "Failed to set mux for cam data 5 pru" );
  if( 0 != system( "echo 36 > /sys/kernel/debug/omap_mux/lcd_data6" ) )
    throw std::runtime_error( "Failed to set mux for cam data 6 pru" );
  if( 0 != system( "echo 36 > /sys/kernel/debug/omap_mux/lcd_data7" ) )
    throw std::runtime_error( "Failed to set mux for cam data 7 pru" );
  if( 0 != system( "echo 36 > /sys/kernel/debug/omap_mux/lcd_vsync" ) )
    throw std::runtime_error( "Failed to set mux for cam vsync pru" );
  if( 0 != system( "echo 36 > /sys/kernel/debug/omap_mux/lcd_hsync" ) )
    throw std::runtime_error( "Failed to set mux for cam hsync pru" );
  if( 0 != system( "echo 36 > /sys/kernel/debug/omap_mux/uart1_rxd" ) )
    throw std::runtime_error( "Failed to set mux for cam clock pru" );





  std::ofstream cam_reset( "/sys/class/gpio/gpio88/value" );
  std::ofstream cam_led( "/sys/class/gpio/gpio61/value" );
  std::ofstream cam_data( "/sys/class/gpio/gpio69/value" );
  
  if( !cam_reset.is_open() || !cam_led.is_open() || !cam_data.is_open() )
    throw std::runtime_error( "Failed to open cam gpios" );

  cam_reset << '1' << std::endl;
  cam_led << '1' << std::endl;
  cam_data << '0' << std::endl;
  
  
  
  
  
  
  
  
  
  
  
  
  
  
  
  system("modprobe uio_pruss");
 
  unsigned int ret;
  tpruss_intc_initdata pruss_intc_initdata = PRUSS_INTC_INITDATA;
  prussdrv_init ();		

  if( 0 != prussdrv_open(PRU_EVTOUT_0) )
    throw std::runtime_error( "Failed to open pru0" );
  if( 0 != prussdrv_open(PRU_EVTOUT_1) )
    throw std::runtime_error( "Failed to open pru1" );

  prussdrv_pruintc_init(&pruss_intc_initdata);

  volatile uint32_t *pru0_data, *pru1_data, *pru_shared;
  
  prussdrv_map_prumem (PRUSS0_PRU0_DATARAM, (void**)&pru0_data);
  prussdrv_map_prumem (PRUSS0_PRU1_DATARAM, (void**)&pru1_data);
  prussdrv_map_prumem(PRUSS0_SHARED_DATARAM, (void**)&pru_shared);
  
  memset( (void*)pru0_data, 0, 8*1024);
  memset( (void*)pru1_data, 0, 8*1024);
  memset( (void*)pru_shared, 0, 12*1024);

  volatile uint16_t *pru0_ddr, *pru1_ddr;	

  int mem_fd = open("/dev/mem", O_RDWR);
  if (mem_fd < 0)
    throw std::runtime_error( "Failed to open /dev/mem" );

  pru0_ddr= (uint16_t*)mmap(0, PRU_DDR_SIZE, PROT_WRITE | PROT_READ, MAP_SHARED, mem_fd, PRU0_DDR);
  if (pru0_ddr == NULL)
    throw std::runtime_error( "Failed to map pru0 ddr" );
    
  pru1_ddr= (uint16_t*)mmap(0, PRU_DDR_SIZE, PROT_WRITE | PROT_READ, MAP_SHARED, mem_fd, PRU1_DDR);
  if (pru1_ddr == NULL)
    throw std::runtime_error( "Failed to map pru1 ddr" );
    
    
  memset( (void*)pru0_ddr, 0, PRU_DDR_SIZE);
  memset( (void*)pru1_ddr, 0, PRU_DDR_SIZE);
    
    
    
    
    
    
  
  
int i=0, n=0, readcnt=1;
  
  // initialization: open port, ioctl address, send 0x40/0x00 init to nunchuck:
  int fd_accel_303 = open(PORT, O_RDWR);
  if(fd_accel_303<0) error("cant open %s - %m", PORT);
  if(ioctl(fd_accel_303, I2C_SLAVE, ADDR_ACCEL_303) < 0) error("cant ioctl %s:0x%02x - %m", PORT, ADDR_ACCEL_303);
  
  int fd_mag_303 = open(PORT, O_RDWR);
  if(fd_mag_303<0) error("cant open %s - %m", PORT);
  if(ioctl(fd_mag_303, I2C_SLAVE, ADDR_MAG_303) < 0) error("cant ioctl %s:0x%02x - %m", PORT, ADDR_MAG_303);
  
  int fd_accel_330 = open(PORT, O_RDWR);
  if(fd_accel_330<0) error("cant open %s - %m", PORT);
  if(ioctl(fd_accel_330, I2C_SLAVE, ADDR_ACCEL_330) < 0) error("cant ioctl %s:0x%02x - %m", PORT, ADDR_ACCEL_330);
  
  int fd_gyro_330 = open(PORT, O_RDWR);
  if(fd_gyro_330<0) error("cant open %s - %m", PORT);
  if(ioctl(fd_gyro_330, I2C_SLAVE, ADDR_GYRO_330) < 0) error("cant ioctl %s:0x%02x - %m", PORT, ADDR_GYRO_330);
  
  int fd_cam = open(PORT, O_RDWR);
  if(fd_cam<0) error("cant open %s - %m", PORT);
  if(ioctl(fd_cam, I2C_SLAVE, ADDR_CAM) < 0) error("cant ioctl %s:0x%02x - %m", PORT, ADDR_CAM);
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

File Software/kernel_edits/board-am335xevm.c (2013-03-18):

/*
 * Code for AM335X EVM.
 *
 * Copyright (C) 2011 Texas Instruments, Inc. - http://www.ti.com/
 *
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
 * This program is distributed "as is" WITHOUT ANY WARRANTY of any
 * kind, whether express or implied; without even the implied warranty
 * of MERCHANTABILITY or FITNESS FOR A PARTICULAR PURPOSE.  See the
 * GNU General Public License for more details.
 */
#include <linux/kernel.h>
#include <linux/init.h>
#include <linux/i2c.h>
#include <linux/module.h>
#include <linux/i2c/at24.h>
#include <linux/phy.h>
#include <linux/gpio.h>
#include <linux/leds.h>
#include <linux/spi/spi.h>
#include <linux/spi/flash.h>
#include <linux/gpio_keys.h>
#include <linux/input.h>
#include <linux/input/matrix_keypad.h>
#include <linux/mtd/mtd.h>
#include <linux/mtd/nand.h>
#include <linux/mtd/partitions.h>
#include <linux/platform_device.h>
#include <linux/clk.h>
#include <linux/err.h>
#include <linux/wl12xx.h>
#include <linux/ethtool.h>
#include <linux/mfd/tps65910.h>
#include <linux/mfd/tps65217.h>
#include <linux/pwm_backlight.h>
#include <linux/reboot.h>
#include <linux/pwm/pwm.h>
#include <linux/opp.h>
#include <linux/w1-gpio.h>
#include <linux/can/platform/mcp251x.h>
#include <linux/input/ti_tscadc.h>

#include <sound/tlv320aic3x.h>

/* LCD controller is similar to DA850 */
#include <video/da8xx-fb.h>

#include <mach/hardware.h>
#include <mach/board-am335xevm.h>

#include <asm/mach-types.h>
#include <asm/mach/arch.h>
#include <asm/mach/map.h>
#include <asm/hardware/asp.h>

#include <plat/omap_device.h>
#include <plat/irqs.h>
#include <plat/board.h>
#include <plat/common.h>
#include <plat/lcdc.h>
#include <plat/usb.h>
#include <plat/mmc.h>
#include <plat/emif.h>
#include <plat/nand.h>
#include <plat/dma-33xx.h>

#include <media/soc_camera.h>
#include <media/mt9t112.h>

#include "board-flash.h"
#include "cpuidle33xx.h"
#include "mux.h"
#include "devices.h"
#include "hsmmc.h"

/* Convert GPIO signal to GPIO pin number */
#define GPIO_TO_PIN(bank, gpio) (32 * (bank) + (gpio))

/* TLK PHY IDs */
#define TLK110_PHY_ID		0x2000A201
#define TLK110_PHY_MASK		0xfffffff0

/* BBB PHY IDs */
#define BBB_PHY_ID		0x7c0f1
#define BBB_PHY_MASK		0xfffffffe

/* TLK110 PHY register offsets */
#define TLK110_COARSEGAIN_REG	0x00A3
#define TLK110_LPFHPF_REG	0x00AC
#define TLK110_SPAREANALOG_REG	0x00B9
#define TLK110_VRCR_REG		0x00D0
#define TLK110_SETFFE_REG	0x0107
#define TLK110_FTSP_REG		0x0154
#define TLK110_ALFATPIDL_REG	0x002A
#define TLK110_PSCOEF21_REG	0x0096
#define TLK110_PSCOEF3_REG	0x0097
#define TLK110_ALFAFACTOR1_REG	0x002C
#define TLK110_ALFAFACTOR2_REG	0x0023
#define TLK110_CFGPS_REG	0x0095
#define TLK110_FTSPTXGAIN_REG	0x0150
#define TLK110_SWSCR3_REG	0x000B
#define TLK110_SCFALLBACK_REG	0x0040
#define TLK110_PHYRCR_REG	0x001F

/* TLK110 register writes values */
#define TLK110_COARSEGAIN_VAL	0x0000
#define TLK110_LPFHPF_VAL	0x8000
#define TLK110_SPANALOG_VAL	0x0000
#define TLK110_VRCR_VAL		0x0008
#define TLK110_SETFFE_VAL	0x0605
#define TLK110_FTSP_VAL		0x0255
#define TLK110_ALFATPIDL_VAL	0x7998
#define TLK110_PSCOEF21_VAL	0x3A20
#define TLK110_PSCOEF3_VAL	0x003F
#define TLK110_ALFACTOR1_VAL	0xFF80
#define TLK110_ALFACTOR2_VAL	0x021C
#define TLK110_CFGPS_VAL	0x0000
#define TLK110_FTSPTXGAIN_VAL	0x6A88
#define TLK110_SWSCR3_VAL	0x0000
#define TLK110_SCFALLBACK_VAL	0xC11D
#define TLK110_PHYRCR_VAL	0x4000

#if defined(CONFIG_TLK110_WORKAROUND) || \
		defined(CONFIG_TLK110_WORKAROUND_MODULE)
#define am335x_tlk110_phy_init()\
	do {	\
		phy_register_fixup_for_uid(TLK110_PHY_ID,\
					TLK110_PHY_MASK,\
					am335x_tlk110_phy_fixup);\
	} while (0);
#else
#define am335x_tlk110_phy_init() do { } while (0);
#endif

static const struct display_panel disp_panel = {
	WVGA,
	32,
	32,
	COLOR_ACTIVE,
};


#if defined(CONFIG_CHARGER_GPIO)

#include <linux/power_supply.h>
#include <linux/power/gpio-charger.h>

/* charger */
static char *beaglebone_batteries[] = {
	"battery",
};

static struct gpio_charger_platform_data beaglebone_charger_pdata = {
	.name = "battery-cape",
	.type = POWER_SUPPLY_TYPE_BATTERY,
	.gpio = GPIO_TO_PIN(1,16),
	.gpio_active_low = 0,
	.supplied_to = beaglebone_batteries,
	.num_supplicants = ARRAY_SIZE(beaglebone_batteries),
};

static struct platform_device beaglebone_charger_device = {
	.name = "gpio-charger",
	.dev = {
		.platform_data = &beaglebone_charger_pdata,
	},
};

#endif /* gpio-charger */


/* LCD backlight platform Data */
#define AM335X_BACKLIGHT_MAX_BRIGHTNESS        100
#define AM335X_BACKLIGHT_DEFAULT_BRIGHTNESS    50
#define AM335X_PWM_PERIOD_NANO_SECONDS        (1000000 * 5)

#define PWM_DEVICE_ID   "ecap.0"

static struct platform_pwm_backlight_data am335x_backlight_data = {
	.pwm_id         = PWM_DEVICE_ID,
	.ch             = -1,
	.lth_brightness	= 21,
	.max_brightness = AM335X_BACKLIGHT_MAX_BRIGHTNESS,
	.dft_brightness = AM335X_BACKLIGHT_DEFAULT_BRIGHTNESS,
	.pwm_period_ns  = AM335X_PWM_PERIOD_NANO_SECONDS,
};

static const struct display_panel bbtoys7_panel = {
	WVGA,
	16,
	16,
	COLOR_ACTIVE,
};
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

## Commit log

2013-01-01 Design complete, cleanup needed.
    [interacto.brd, interacto.sch, interacto.xlsx]
2013-01-01 BOM done.
    [interacto.brd, interacto.sch, interacto.xls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]
2013-01-06 Adding BOM prices, adding PDFs of design, sorting files, adding software.
    [interacto.brd, interacto.sch, interacto.xls]
2013-03-18 Updates from prototype build and testing.
    [BOM.xls, interacto.brd, interacto.sch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]

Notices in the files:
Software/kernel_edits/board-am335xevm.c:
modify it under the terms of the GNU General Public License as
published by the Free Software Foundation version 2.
